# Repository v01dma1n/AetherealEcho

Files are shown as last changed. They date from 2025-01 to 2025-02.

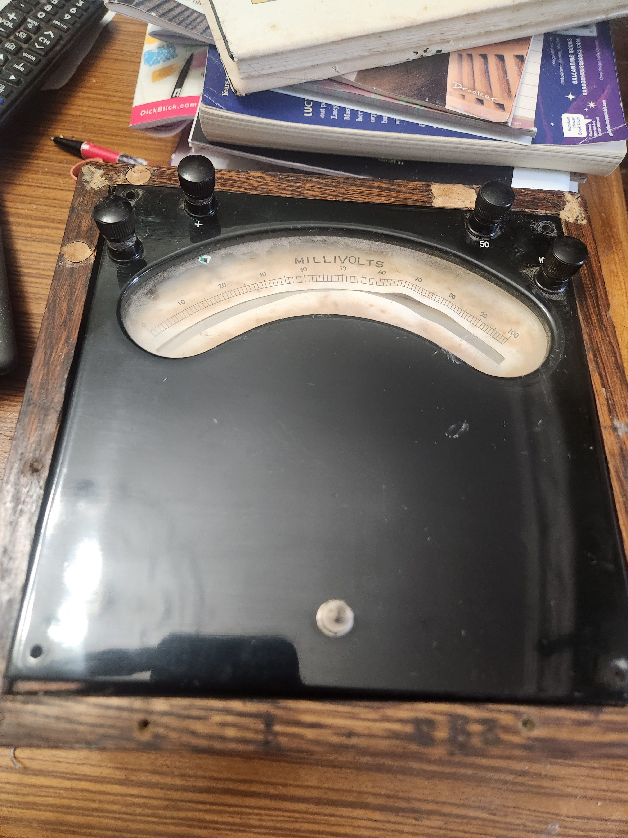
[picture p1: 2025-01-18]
Photos/20241117_153411.jpg

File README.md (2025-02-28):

# **Aethereal Echo: ESP32-Based Wi-Fi and Ping Monitor**

The Aethereal Echo is a project that combines modern technology with a vintage aesthetic. It utilizes an **ESP32** microcontroller to create a Wi-Fi and ping monitor, all housed within a nearly **100-year-old millivolt meter** original oak wood box.

## **Key Functions**

### **Wi-Fi Connection and Network Configuration**
*   Upon startup, the Aethereal Echo attempts to connect to a preconfigured local **Wi-Fi network**.
*   If the device cannot connect to the configured network, it activates an **Access Point (AP)**, broadcasting an SSID named "aethereal-echo".
*   Users can connect to this Wi-Fi network and access a configuration page at the IP address **192.168.4.1** via a web browser.
*   The configuration page allows users to input the local Wi-Fi network's name (SSID) and password. After submitting this information, the ESP32 will reboot and attempt to connect to the specified Wi-Fi network.

### **Pinging Predefined Servers**
*   The Aethereal Echo periodically pings a configurable server.
*   The time between pings can be set in the device's settings.
*   If a ping is successful, the meter's needle displays the **ping time** on its scale. A short **ping sound** is also played as confirmation.
*   If a ping times out, the meter indicates an "**Echo Timeout**" by moving to the maximum position on its scale (1000 mTicks), accompanied by a 'sad' sound.
*   After several consecutive failed pings, Aethereal Echo initiates an alert with a sound and **alternating red and blue flashing LEDs**.
*   Following an alert, the device automatically switches to the next configured **ping server** and reboots. There are four ping server addresses that can be configured.

### **Wi-Fi Access Monitoring**
*   After a successful initial connection to a Wi-Fi network, the Aethereal Echo continuously monitors its connection status.
*   If the Wi-Fi connection is lost, the meter indicates an "**No WiFi**" by moving to the maximum position on its scale (0 mTicks) and the device initiates an alert, which includes a sound and alternating red and blue flashing LEDs.
*   The device will attempt to reconnect to the Wi-Fi network or reboot if reconnection fails.

### **Touch Controls**
*   The Aethereal Echo has four touch-sensitive terminals on the front panel.
*   These terminals are used to control the device:
    *   **Activate Access Point**
    *   **Select Target Server IP for Pinging**
    *   **Turn On or Off Ping Sound**
    *   **Turn On or Off Alert Sound**
*   Each function is activated by a **'long touch'**, which is a touch of at least 3 seconds.
*   After a function is activated, the Aethereal Echo will confirm with a sound.
*   Value changes can be achieved by a **'short touch'**, which is a touch of less than 0.5 seconds.
*   The Access Point function does not have 'short touch' settings and is activated immediately by a 'long touch'.
*   Aetheral Echo confirms value change with a sound and meter indication.
*   When changing the target server IP, the device will play a sound, the meter will point to the selected server and a light will turn on in the color associated with the target server.
*   When turning the ping or alert sound on and off, the meter will point to 'Yes' or 'No', and a corresponding sound will play.

#### **Detailed Touch Control Instructions**

*   **Turning on the Access Point:** Use a 'long touch' on the Access Point touch terminal. Upon successful activation, the device will confirm with a sound. While the Access Point is running, you can exit and reboot the device with another 'long touch'. See "Access Point Captive Portal" for details.
*   **Changing the target ping server**: To enter ping server selection mode, use a 'long touch' on the Ping server touch terminal. The device will confirm with a sound, turn a light on in the color of the currently selected ping server, and the meter will indicate the ping server on its scale. To advance to the next ping server, use a 'short touch'. The selection will cycle through the 4 available addresses. You can exit the selection mode with a 'long touch' or by waiting 30 seconds. The device will then resume pinging.
*   **Turning on and off the Ping sound**: To enter the ping sound selection mode, use a 'long touch' on the Ping Sound touch terminal. The device will confirm with a sound, and the meter will indicate the current value ('Yes' or 'No') accompanied by a sound. Use a 'short touch' to toggle the ping sound on and off. The meter will adjust and a corresponding sound will play with each change. You can exit the selection mode with a 'long touch' or by waiting 30 seconds.
*   **Turning on and off the Alert sound**: To enter the alert sound selection mode, use a 'long touch' on the Alert Sound touch terminal. The device will confirm with a sound, and the meter will indicate the current value ('Yes' or 'No') accompanied by a sound. Use a 'short touch' to toggle the alert sound on and off. The meter will adjust and a corresponding sound will play with each change. You can exit the selection mode with a 'long touch' or by waiting 30 seconds.

### Turning on and off top light
-

### Receiving serial log through USB port
-

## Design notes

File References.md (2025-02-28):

# Aethereal Echo
List of external resources used during development of Aethereal Echo.

## GitHub
        https://github.com/v01dma1n/AetherealEcho

## Hardware
  HiLetgo ESP-WROOM-32 ESP32 ESP-32S Development Board
  HiLetgo 5V One Channel Relay Module

## Libraries
- ESP-idf-v5.3
        https://github.com/espressif/esp-idf
- Arduino-ESP32 v.3.0.7 
        https://github.com/espressif/arduino-esp32
- AsyncTCP 1.1.4 
	https://github.com/dvarrel/AsyncTCP
- ESP Async Webserver 3.6.0
	https://github.com/mathieucarbou/ESPAsyncWebServer
- ESP32Logger 1.0.3
	https://github.com/zimbora/ESP32Logger2
- ESPPing 1.0.5
	https://github.com/zimbora/ESP32Logger2
- SimpleFSM 1.3.1
	https://github.com/LennartHennigs/SimpleFSM
- Preferences v.3.1.1
- FS v.3.1.1 
- WiFi v.3.1.1 
- Networking v.3.1.1 
- DNSServer v.3.1.1 
- ESP32 Async UDP v.3.1.1 

## 3D Models
  - 5v Relay Box - One Channel Relay Module by parrothd
  	- https://www.printables.com/model/377681-5v-relay-box-one-channel-relay-module

## Textures
  - https://freestocktextures.com/texture/old-yellowed-paper,1340.html#google_vignette

## Ornaments
  - https://www.vectorian.net/free-vintage-vectors.html
  
## Vectorizer
  - https://vectorizer.com/
        
## Fonts
  - https://www.fontspace.com/search?q=victorian

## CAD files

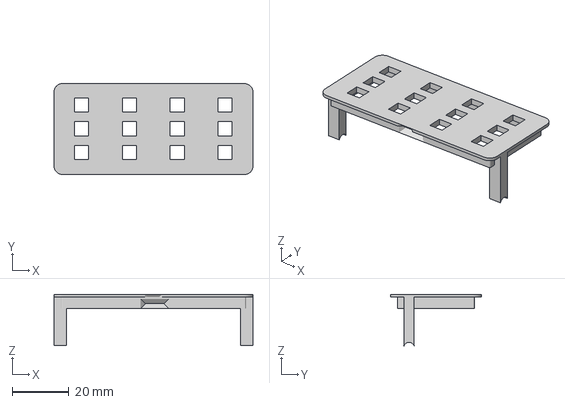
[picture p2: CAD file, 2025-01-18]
3D Print/5v-relay-box-one-channel-relay-module-model_files/5v-Relay-Top.3mf
70.0 x 32.0 x 18.0 mm

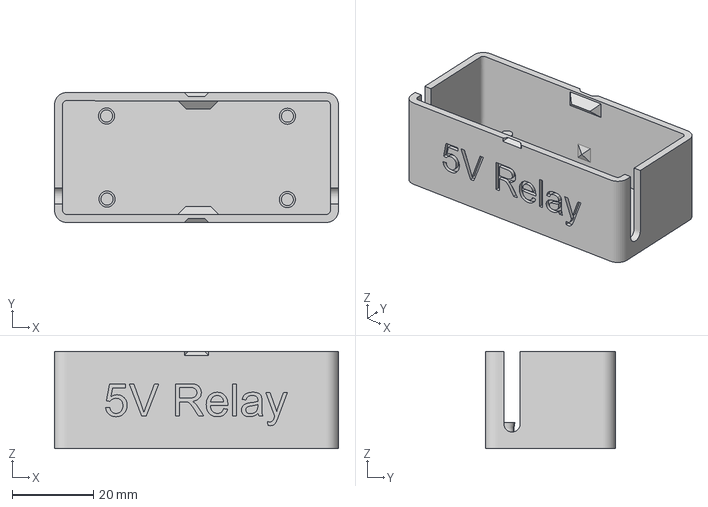
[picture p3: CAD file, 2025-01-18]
3D Print/5v-relay-box-one-channel-relay-module-model_files/5v-Relay-Box.3mf
70.0 x 32.0 x 24.0 mm

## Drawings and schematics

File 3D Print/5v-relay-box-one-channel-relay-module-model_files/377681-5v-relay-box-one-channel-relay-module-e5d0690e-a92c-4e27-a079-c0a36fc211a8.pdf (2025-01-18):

## 5v Relay Box - One

## Channel Relay

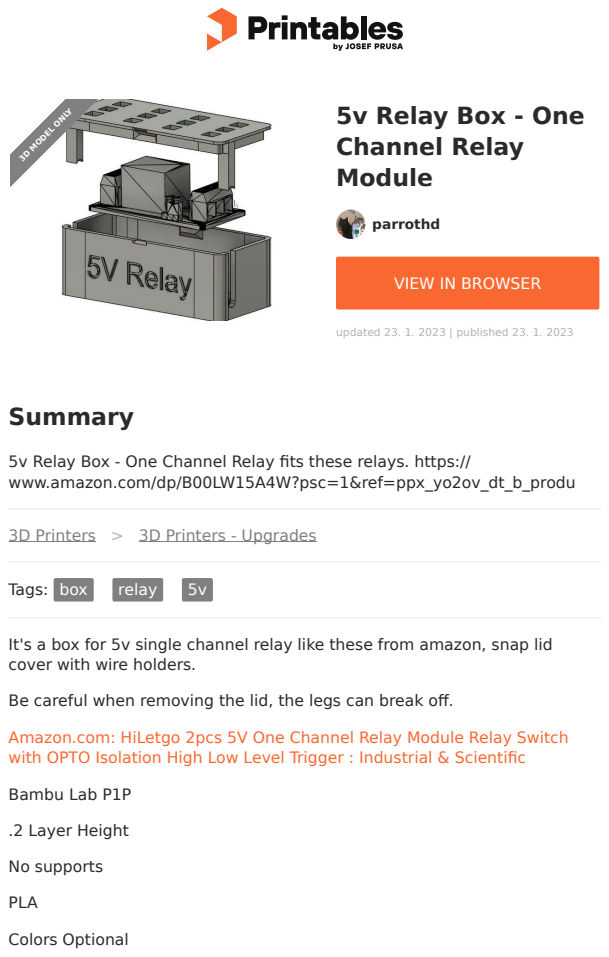
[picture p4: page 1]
Summary; Tags: box; relay; Bambu Lab P1P; .2 Layer Height; No supports; PLA; Colors Optional; parrothd; Module; updated 23. 1. 2023 | published 23. 1. 2023; 3D MODEL ONLY

VIEW IN BROWSER (https://printables.com/model/377681-5v-relay-box-one-channel-relay-module)

5v Relay Box - One Channel Relay fits these relays. https://
www.amazon.com/dp/B00LW15A4W?psc=1&ref=ppx_yo2ov_dt_b_produ

3D Printers (https://printables.com/model?categoryId=1) > 3D Printers - Upgrades (https://printables.com/model?categoryId=2)

It's a box for 5v single channel relay like these from amazon, snap lid
cover with wire holders.

Be careful when removing the lid, the legs can break off.

Amazon.com: HiLetgo 2pcs 5V One Channel Relay Module Relay Switch
with OPTO Isolation High Low Level Trigger : Industrial & Scientific (https://www.amazon.com/dp/B00LW15A4W?psc=1&ref=ppx_yo2ov_dt_b_product_details)

## Model files

## License

This work is licensed under a
Creative Commons (4.0 International License)

Attribution (http://creativecommons.org/licenses/by/4.0/)

✖ | Sharing without ATTRIBUTION
✔ | Remix Culture allowed
✔ | Commercial Use
✔ | Free Cultural Works
✔ | Meets Open Definition

5v-relay-box.3mf

5v-relay-top.3mf

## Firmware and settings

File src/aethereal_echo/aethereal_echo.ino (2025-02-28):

#define ESP32DEBUGGING
#include <ESP32Logger.h>

#include "access_point.h"
#include "ae_fsm_config.h"
#include "aethereal_echo.h"
#include "app_pref.h"
#include "led_rgb.h"
#include "melody.h"
#include "meter_output.h"
#include "sntp_timer.h"
#include "touch_timer.h"
#include "version.h"

MeterOutput meterOutTimer(100, GPIO_PWM); // update output
LedRGB pingRGBTimer1(10, GPIO_LED1_R, GPIO_LED1_G, GPIO_LED1_B);
LedRGB pingRGBTimer2(10, GPIO_LED2_R, GPIO_LED2_G, GPIO_LED2_B);

#define SCALE_LED_PERIOD_MS 3000

RGB pingIPColors[PING_IP_COUNT];
float pingIPMeter[PING_IP_COUNT];

TimerMillis debugTimer(3000);

bool wifiActive = false;
int apReboot = 0;
// bool dnsSelectionActive = false;

int touchThreshold = 40;
bool touch1detected = false;
bool touch2detected = false;
bool touch3detected = false;
bool touch4detected = false;

TouchTimer touchAPTimer(TOUCH_TIMER_MILLIS, T4);
TouchTimer touchDNSTimer(TOUCH_TIMER_MILLIS, T5);
TouchTimer touchAlertEnabledTimer(TOUCH_TIMER_MILLIS, T6);
TouchTimer touchPingSoundTimer(TOUCH_TIMER_MILLIS, T7);

double colorRed = 0, colorGreen = 0, colorBlue = 0;

String ip2Str(IPAddress ip) {
  String s = "";
  for (int i = 0; i < 4; i++) {
    s += i ? "." + String(ip[i]) : String(ip[i]);
  }
  return s;
}

//#define CALIBRATION

#ifdef CALIBRATION

struct CalibrationStep {
  int outputValue; // Value to set the meter output
  int delayTime; 
  // String stepName; // Descriptive name for the step
};

const int numCalibrationSteps = 5; 
std::vector<CalibrationStep> calibrationSteps;

void calibrationSetup() {
  calibrationSteps.push_back({   1, 5000});
  calibrationSteps.push_back({  10, 5000});
  calibrationSteps.push_back({ 100, 5000});
  calibrationSteps.push_back({ 500, 5000});
  calibrationSteps.push_back({1000, 5000});
}

int calibrationStep {0};
unsigned long lastCalibrationStepMillis {0};

void calibrationLoop() {

  const CalibrationStep& currentStep = calibrationSteps[calibrationStep];

  if (lastCalibrationStepMillis + currentStep.delayTime < millis())
  {
    lastCalibrationStepMillis = millis();
    calibrationStep++;
    if (calibrationStep >= numCalibrationSteps)
      calibrationStep = 0;

    DBGLOG(Info, "Step: %d", calibrationStep);
    meterOutTimer.setOutput(currentStep.outputValue);
  }
}
#endif // CALIBRATION


void setup() {

  // Serial.begin(115200);
  Serial.begin(19200);
  while (!Serial)
    delay(300);

  randomSeed(0);

  // Initialize debugging with timestamp since start (start = 0)
  DBGINI(&Serial, ESP32Timestamp::TimestampSinceStart)
  DBGLEV(Error);
  // Start debugging
  DBGSTA
  DBGLOG(Info, "Starting")

  appPrefs.setup();
  appPrefs.getPreferences();
  appPrefs.dumpPreferences();
  // change the log level based on the configuration
  Log.setLogLevel(ESP32LogLevel(appPrefs.config.logLevel));

  pingIPColors[0] = {1, 0, 0}; // Red
  pingIPColors[1] = {0, 1, 0}; // Green
  pingIPColors[2] = {0, 0, 1}; // Blue
  pingIPColors[3] = {1, 1, 1}; // White

  pingIPMeter[0] = AE_OUTPUT_BEACON1;
  pingIPMeter[1] = AE_OUTPUT_BEACON2;
  pingIPMeter[2] = AE_OUTPUT_BEACON3;
  pingIPMeter[3] = AE_OUTPUT_BEACON4;

  // strncpy(appPrefs.config.ssid, "", sizeof(appPrefs.config.ssid));
  // strncpy(appPrefs.config.password, "", sizeof(appPrefs.config.password));
  // appPrefs.putPreferences();

  debugTimer.setCanRestart(true);
  debugTimer.timerStart();

  aeFsmSetup();
#ifdef DEBUG_FSM_GRAPH
  String fsmGraph = aeShowGraph();
  // DBGLOG(Debug, "%s\n", fsmGraph.c_str())
  Serial.println(fsmGraph.c_str());
#endif

  pinMode(GPIO_SWITCH, INPUT);
  pinMode(GPIO_SWITCH, INPUT_PULLUP);
  pinMode(GPIO_LAMP, OUTPUT);
  pinMode(GPIO_BUZZER, OUTPUT);
  pinMode(GPIO_LED3, OUTPUT);

  meterOutTimer.setup();
  pingRGBTimer1.setup();
  pingRGBTimer2.setup();

  digitalWrite(GPIO_LED3, 1); // turn on the backlight

  touchAPTimer.setup();
  touchAttachInterrupt(T7, gotTouch1, touchThreshold);
  touchAttachInterrupt(T6, gotTouch2, touchThreshold);
  touchAttachInterrupt(T5, gotTouch3, touchThreshold);
  touchAttachInterrupt(T4, gotTouch4, touchThreshold);

  meterOutTimer.timerOutputMillis.timerStart();
  pingRGBTimer1.timerOutputMillis.timerStart();
  pingRGBTimer2.timerOutputMillis.timerStart();

  touchAPTimer.timerMillis.timerStart();
  touchDNSTimer.timerMillis.timerStart();
  touchPingSoundTimer.timerMillis.timerStart();
  touchAlertEnabledTimer.timerMillis.timerStart();

  // Log an info-message
  DBGLOG(Info, "\n%s v.%s, %s, %s\n", APP_NAME, VERSION_STRING.c_str(),
         APP_DATE, APP_AUTHOR)

#ifdef CALIBRATION
  calibrationSetup();
#endif

} // setup()

void gotTouch1() { touch1detected = true; }
void gotTouch2() { touch2detected = true; }
void gotTouch3() { touch3detected = true; }
void gotTouch4() { touch4detected = true; }

#ifdef CALIBRATION
void loop() {

  calibrationLoop();

  // if (wifiActive) {
  //   if (timeAvail)
  //     loopSntpGetTime(NTP_REFRESH_INTERVAL_MILLIS);
  // }

  meterOutTimer.loop();
}

#else // not a CALIBRATION - normal function

void loop() {

  aeFsmLoop();

  if (wifiActive) {
    if (timeAvail)
      loopSntpGetTime(NTP_REFRESH_INTERVAL_MILLIS);
  }

  // turn on and of the lamp based on the manual switch state
  int switchState = digitalRead(GPIO_SWITCH);
  digitalWrite(GPIO_LAMP, !switchState);

  pingRGBTimer1.loop();
  pingRGBTimer2.loop();
  meterOutTimer.loop();

  melody_loop();

  if (touch1detected) {
    touch1detected = false;
  }
  if (touch2detected) {
    touch2detected = false;
  }
  if (touch3detected) {
    touch3detected = false;
  }
  if (touch4detected) {
    touch4detected = false;
  }

  // Check if we need to activate the access point
  if (touchAPTimer.loop()) {
    if (touchAPTimer.isShortTouch) {
      DBGLOG(Debug, "Short Touch: AP");
    } else if (touchAPTimer.isLongTouch) {
      DBGLOG(Debug, "Long Touch: AP");
      fsm.trigger(tr_ap_long_press);
      touchAPTimer.reset();
    }
  }

  if (touchDNSTimer.loop()) {
    if (touchDNSTimer.isShortTouch) {
      DBGLOG(Debug, "Short Touch: DNS");
      fsm.trigger(tr_ip_select_short_press);
      touchDNSTimer.reset();
    } else if (touchDNSTimer.isLongTouch) {
      DBGLOG(Debug, "Long Touch: DNS");
      fsm.trigger(tr_ip_select_long_press);
      touchDNSTimer.reset();
    }
  }

  if (touchPingSoundTimer.loop()) {
    if (touchPingSoundTimer.isShortTouch) {
      DBGLOG(Debug, "Short Touch: ping sound");
      fsm.trigger(tr_ping_sound_short_press);
      touchPingSoundTimer.reset();
    } else if (touchPingSoundTimer.isLongTouch) {
      DBGLOG(Debug, "Long Touch: ping sound");
      fsm.trigger(tr_ping_sound_long_press);
      touchPingSoundTimer.reset();
    }
  }

  if (touchAlertEnabledTimer.loop()) {
    if (touchAlertEnabledTimer.isShortTouch) {
      DBGLOG(Debug, "Short Touch: alert enabled");
      fsm.trigger(tr_alert_enabled_short_press);
      touchAlertEnabledTimer.reset();
    } else if (touchAlertEnabledTimer.isLongTouch) {
      DBGLOG(Debug, "Long Touch: alert enabled");
      fsm.trigger(tr_alert_enabled_short_press);
      touchAlertEnabledTimer.reset();
    }
  }
}

#endif

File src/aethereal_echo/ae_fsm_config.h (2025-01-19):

#ifndef AE_FSM_CONFIG_H
#define AE_FSM_CONFIG_H

#include "SimpleFSM.h"
#include "State.h"

extern SimpleFSM fsm;

#define FSM_RUN_MILLIS 100

// timed transition times
#define WIFI_CONNECTED_TO_PING_MILLIS 3 * 1000
#define AP_RUNNING_TO_REBOOT 3 * 60 * 1000
#define IP_SELECT_TO_WIFI_CONNECTED_MILLIS 30 * 1000
#define PING_SOUND_SELECT_TO_WIFI_CONNECTED_MILLIS 20 * 1000
#define ALERT_ENABLED_SELECT_TO_WIFI_CONNECTED_MILLIS 20 * 1000
#define WIFI_ALERT_TOGGLE_MILLIS 250
#define PING_ALERT_MILLIS 3 * 1000
#define WIFI_ALERT_TO_DISCONNECTED_MILLIS 20 * 1000
#define WIFI_DISCONNECTED_TO_REBOOT_MILLIS 10 * 1000

enum stateName {
    ST_BOOT,
    ST_WIFI_CONNECTED,
    ST_AP_RUNNING,
    ST_PING,
    ST_PING_ALERT,
    ST_IP_SELECT,
    ST_IP_NEXT,
    ST_PING_SOUND_SELECT,
    ST_PING_SOUND_TOGGLE,
    ST_ALERT_ENABLED_SELECT,
    ST_ALERT_ENABLED_TOGGLE,
    ST_WIFI_ALERT,
    ST_WIFI_ALERT_TOGGLE,
    ST_WIFI_DISCONNECTED,
    ST_REBOOT,
    NUM_OF_STATES
};

enum triggers {
    tr_wifi_connected = 1,
    tr_wifi_not_connected,
    tr_wifi_lost,
    tr_wifi_alert_end,
    tr_wifi_alert_toggle_end,
    tr_wifi_reconnected,
    tr_ap_config_ok,
    tr_ap_config_err,
    tr_ping_timeout,
    tr_ping_ok,
    tr_ping_alert_end,
    tr_ping_timeout_max,
    tr_ap_long_press,
    tr_ap_short_press,
    tr_ip_select_short_press,
    tr_ip_select_long_press,
    tr_ip_select_done,
    tr_ping_sound_short_press,
    tr_ping_sound_long_press,
    tr_ping_sound_select_done,
    tr_alert_enabled_short_press,
    tr_alert_enabled_long_press,
    tr_alert_enabled_select_done
};

enum TimedTransitionName {
    TTR_AP_RUNNING_TO_RESET,
    TTR_WIFI_CONNECTED_TO_PING,
    TTR_PING_ALERT_TO_PING,
    TTR_IP_SELECT_TO_WIFI_CONNECTED,
    TTR_PING_SOUND_SELECT_TO_WIFI_CONNECTED,
    TTR_ALERT_ENABLED_SELECT_TO_WIFI_CONNECTED,
    TTR_WIFI_ALERT_TO_WIFI_ALERT_TOGGLE,
    TTR_WIFI_ALERT_TO_WIFI_DISCONNECTED,
    TTR_WIFI_DISCONNECTED_TO_REBOOT,
    // TTR_PING_SOUND_TOGGLE_TO_PING_SOUND_SELECT,
    NUM_OF_TTR
};

extern TimedTransition timedTransitions[NUM_OF_TTR];

extern void aeFsmSetup();
extern void aeFsmLoop();
extern String aeShowGraph();

#endif // AE_FSM_CONFIG_H

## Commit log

2025-01-17 2025-01-15 v.0.20 Restored defaults for DNS servers - Restored defaults for DNS servers, which were removed after String to char* conversion
2025-01-18 2025-01-16 v.0.21 ae_state_machine is now split - ae_state_machine is now split into ae_fsm_config and ae_fsm_execute
2025-01-18 2025-01-17 v.0.1 FSM is now split into config and execute - FSM is now split into config and execute - AE is now on GitHub
2025-01-18 2025-01-18 v.0.22 The FSM graph construction fixed - The FSM graph construction fixed afer the code was lost.
2025-01-18 2025-01-18 v.0.23 No Newline fixed - No Newline fixed - References updated
    [led_rgb.h, meter_output.h]
2025-01-18 Circuit folder renamed to Hardware
2025-01-19 FSM: "switch" word replaced with "toggle"
    [ae_fsm_config.h, ae_fsm_execute.cpp]
2025-02-28 2025-03-01 v.0.24 LedRGB class renaming - Connecting to WiFi melody added. - Scale backlight addedNow using LedRGB class name.
2025-02-28 2025-03-01 v.0.25 Beacon selection meter - Echo Timeout meter value - No Local Beacon meter value
